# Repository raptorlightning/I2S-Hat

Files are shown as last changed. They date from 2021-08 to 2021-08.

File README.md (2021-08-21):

# I<sup>2</sup>SHat
An SPDIF RX and TX I<sup>2</sup>S Hat for the Raspberry Pi 2, 3, 4, etc. -- all versions that uses the same GPIO pinout for I<sup>2</sup>S.

## Overview
This project was developed as a replacement or substitute for the various DSP MCU-based processors available on the market. The goals of the project were:
* Leverage the ever-increasing processing power of the Raspberry Pi platform through CamillaDSP https://github.com/HEnquist/camilladsp for DSP, decoupling the number of filters and processing capability from the available MCU-based solutions.
* Allow digital input and output without resampling or other pre/post-processing.
* Utilize SPDIF from 44.1kHz-192kHz Stereo coaxial and/or optical.
* Automatic detection of the input sample rate and reconfiguration of the digital filters based on the sample rate found.

To make this possible, a combination of software and hardware is required. The schematics and PCB to create the SPDIF hat are provided in KiCAD format in the "I2SHat" folder. Please modify the schematic and PCB as required for component availibility.

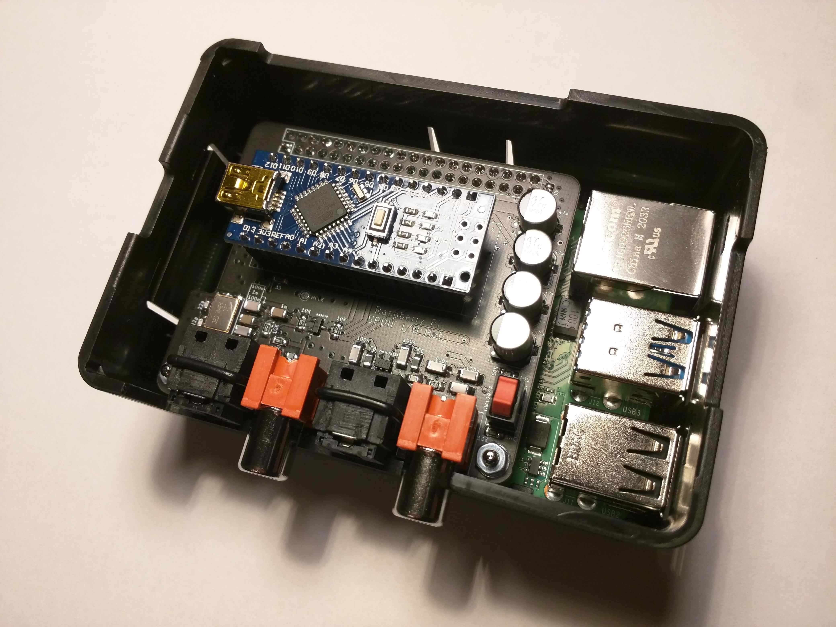
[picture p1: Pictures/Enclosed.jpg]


## Hardware Information
For the PCB, general board rules for sensitive traces should be adhered to as seen in the original design. Extra grounding pads are provided around the SPDIF receiver (WM8804) if physical shielding is needed for nearby EMI components. This has not been a problem with my own testing on a Raspberry Pi 4 Model B above the input buck converter. 
Some BOM cost reductions are as follows:
* Use cheaper 0805 0.1uF X7R decoupling capacitors (>10V), they will work fine with the footprints in the Gerber.
* Don't buffer the inputs before the multiplexer, or use a combined buffer IC. Know the output of your TOSLINK Receiver before you do this.
* Use less expensive decoupling on the output of the 3.3V regulators (see datasheet).

The other aspects of the circuit have been tested and proven. Resistor tolerances are of no concern, neither are capacitor tolerances. Regardless, don't use a 10uF Y5U 5V rated MLCC capacitor for the regulator outputs. That will violate the datasheet.

The SPDIF input and output are tested as shown to work up to 192kHz. Substituting parts (especially the IC types) is discouraged. However, substituing brands or footprints is okay. For example, on the board there is an NXP part in a very small package that is simply a 2:1 LVCMOS mux - NC7SZ157P6X, same as a 74LVC1G157. If you can find a similar part available in a bigger footprint, please edit the board and substitute. The part package size was due to current availability. Only subsitute the unbuffered and buffered inverters on the SPDIF Coaxial input for appropriate unbuffered and buffered parts from other suppliers. Please maintain phase of inputs and outputs if you substitute multi-gate chips and redesign the board.

The footprints provided for TOSLINK are for the TORX142L and TOTX142L, available currently as the Ali-sourced DLR2180 and DLT2180. Unfortunately the market for US/EU TOSLINK receivers at 25mbps bandwidth is largely dead, and the only source is Aixin. Everlight and Toshiba both no longer produce these modules. If you are sourcing from Aixin, ensure that you order a 25mbps module (DLx2xxx) to guarantee 192kHz operation (192*32(Bits/channel)*2(Channels)*2(BMC)=24.576MHz). Modify the footprints as necessary for the TOSLINK module you purchase.

There is a switch on the PCB for the receiver side to choose SPDIF coaxial or TOSLINK input. This is required but can be wired as desired, autodetection is possible, with great modification in hardware or software, but not advised. Generally, one would set up a system with this DSP in a path of specific choosing. The footprint is provided for a GW12RCP equivalent 0.1" microswitch; however, this could be wired to a front panel switch or the Nano itself with further programming and external control. Note that the silkscreen is correct for the switch, but opposite of the connected pads due to the switch mechanics.

If the HifiBerry case (https://www.hifiberry.com/shop/cases/hifiberry-universal-case-black-pi4/) is used, you will need to trim the TOSLINK devices specified. There are 192kHz (25Mbps) TOSLINK transmitters and receivers available from overseas sources in quantity without the screw mounting terminal, but the DLR2180 and DLT2180 TOXX142L equivalents generally have good availability. If you use these substitutes, trim off the screw terminal and add mechanical strength with solid-core wire through the provided holes on the board as shown. If the HifiBerry case is used, pressing down on the top of the case resets the Nano and the WM8804, which might be useful if your Pi takes longer than 45 seconds to start and you don't modify the code (see the INO). There is diode protection for the 5V supply, so you should be able to program the Nano in-circuit (no warranty...) The Pi+Hat+Nano stack is designed to fit in the HifiBerry case with a little extra filing for the TOSLINK connectors on the bottom of the cutout. Height is tight, but it does fit using the standard height board headers specified.

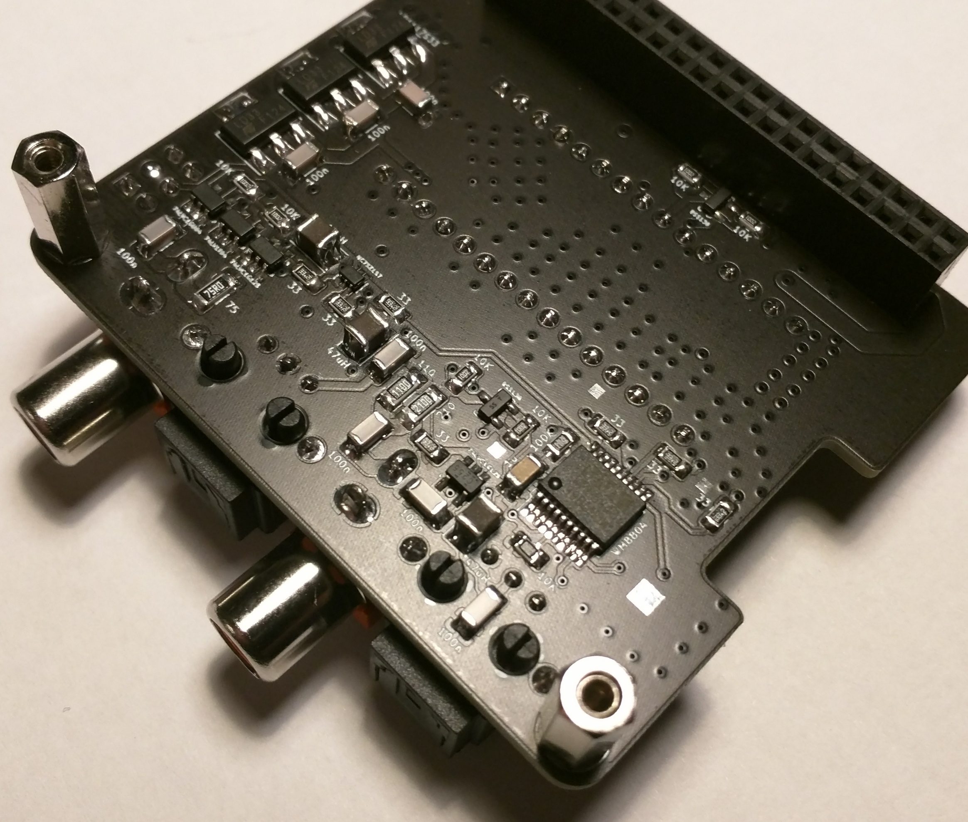
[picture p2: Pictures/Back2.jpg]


## Software Information

You will need to flash the project INO file to an Arduino Nano for control of the WM8804 and sample rate detection. The code and functionality could likely be accomplished with an ATTINY, but for the price and seeing as the footprint fits, a Nano is adequate. See the Arduino documentation for proper flashing of the INO file. Modify as you need for your purposes. 

On the software side of things, the Raspberry Pi must be responsible for receiving I<sup>2</sup>S data, transmitting I<sup>2</sup>S data, and processing it in the middle. Using Ubuntu Server, with a DTS overlay for slave I<sup>2</sup>S operation:

The tested system consists of Ubuntu Server 20.04.2 LTS running on a Raspberry Pi Model 4B. Modifications are posted below:
* Install the required I<sup>2</sup>S Slave DTOverlay at https://github.com/AkiyukiOkayasu/RaspberryPi_I2S_Slave
* Set up CamillaDSP to run as a service on boot through the Python script in the repostiory. There are many different ways to accomplish this, but how it has been tested is through the following (sudo assumed):
  1. Setup WiFi and SSH. I won't illustrate that here as there are many guides available online for it.
  2. Copy the CamillaDSP executable (appropriate to your arch (for RPi4B and Ubuntu Server, it should be aarch64)), startdsp.py, and all of your frequency-specific YML files to a created /etc/camilladsp/ directory.
  3. Create a file in the /etc/systemd/system directory called camilladsp.service that contains the following code:
    * ```
      [Unit]
      Description=CamillaDSP Script Booter
      After=multi-user.target

      [Service]
      ExecStart=/usr/bin/python3 /etc/camilladsp/startdsp.py
      #ExecStart=cat
      StandardOutput=kmsg
      StandardError=kmsg
      Restart=always
      CPUSchedulingPolicy=rr
      CPUSchedulingPriority=99
      IOSchedulingClass=realtime
      IOSchedulingPriority=0

      [Install]
      WantedBy=multi-user.target
    * This ensures that the process (and hopefully subprocess of CamillaDSP) runs without any interruption due to other system services. The point of installing Ubuuntu server is that you will have very few, if any, processes running in the background. All CPU should be dedicated to the DSP.
  4. In the /etc/systemd/system/multi-user.target.wants directory create a symlink using "ln" camilladsp.service to /etc/systemd/system/camilladsp.service to create a link for the target.
* Modify the following in the /boot/firmware directory to enable I<sup>2</sup>S and disable onboard audio (unless you need it).
    * /boot/firmware/syscfg.txt
      *  ```
          \# This file is intended to be modified by the pibootctl utility. User
          \# configuration changes should be placed in "usercfg.txt". Please refer to the
          \# README file for a description of the various configuration files on the boot
          \# partition.

          \#enable_uart=1
          \#dtparam=audio=on
          \#dtparam=i2c_arm=on
          \#dtparam=spi=on
          dtparam=i2s=on
          cmdline=cmdline.txt
          
* Headers for YML files for CamillaDSP include the following since the required DTOverlay is installed (obviously samplerate is file-dependent):
    * ```---
      #You may need to specify chunksize (1024) and target_level (512). See default files and CamillaDSP documentation.
      
      devices:
        samplerate: 44100
        chunksize: 1024
        target_level: 512
        capture:
          type: Alsa
          channels: 2
          device: "hw:CARD=GenericStereoAu,DEV=1"
          format: S32LE
        playback:
          type: Alsa
          channels: 2
          device: "hw:CARD=GenericStereoAu,DEV=0"
          format: S32LE
    
* Set up a Samba share for the /etc/camilladsp directory if you want to remotely access it for uploading new configurations.

## Notes and Addendum
Please play around with the files and let me know if you have any better ideas! At heart, I'm a hardware guy, I make the software to work for what I need but don't go beyond. If you have a better solution for the software or find any holes in my instructions, please reach out. I would like to make this as straightforward as possible for anyone to use.

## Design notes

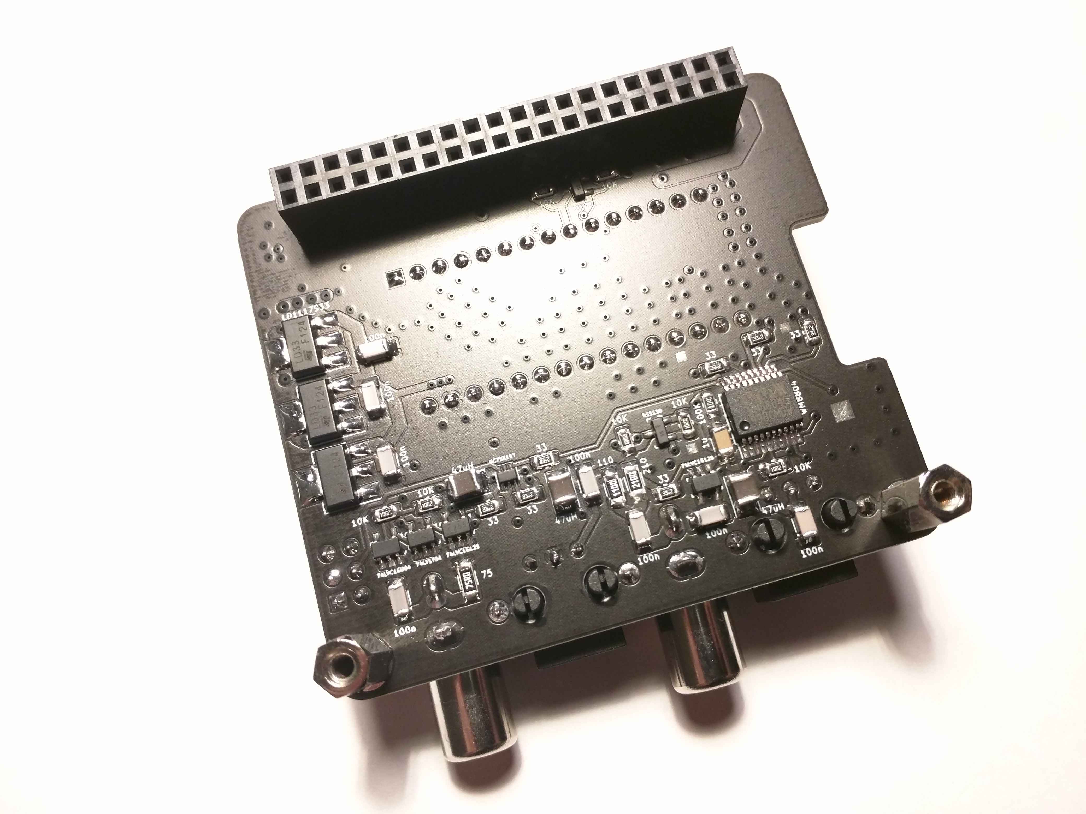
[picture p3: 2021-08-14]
Pictures/Back.jpg

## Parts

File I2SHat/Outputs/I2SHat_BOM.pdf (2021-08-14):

I2SHat

X1 | X2 | Item | Qty | Reference(s) | Value | Footprint
| | 1 | 1 | A1 | Arduino_Nano_v3.x | Module:Arduino_Nano
| | 2 | 16 | C1, C2, C3, C4, C5, C6, C7, C8, C9, C10, C11, C14, C18, C20, C22, C24 | 100n | Capacitor_SMD:C_1206_3216Metric_Pad1.33x1.80mm_HandSolder
| | 3 | 3 | C12, C13, C17 | 1u | Capacitor_SMD:C_1206_3216Metric_Pad1.33x1.80mm_HandSolder
| | 4 | 2 | C15, C16 | 22p | Capacitor_SMD:C_0603_1608Metric_Pad1.08x0.95mm_HandSolder
| | 5 | 4 | C19, C21, C23, C25 | 47u | Capacitor_SMD:C_Elec_6.3x5.8
| | 6 | 1 | D1 | SS1P3L-M3/84A | SS1P3L:SS1P3L-M3&slash_84A
| | 7 | 4 | FB1, FB2, FB3, FB4 | Ferrite_Bead_Small | Resistor_SMD:R_0805_2012Metric_Pad1.20x1.40mm_HandSolder
| | 8 | 2 | H1, H2 | MountingHole | MountingHole:MountingHole_2.7mm_M2.5_Pad
| | 9 | 1 | J1 | TORX142L | Mouser:PLR135T9
| | 10 | 1 | J2 | TOTX142L | Mouser:PLR135T9
| | 11 | 1 | J3 | TX_RCA | Mouser:CUI_RCJ-04X
| | 12 | 1 | J4 | Raspberry_Pi_2_3 | Connector_PinHeader_2.54mm:PinHeader_2x20_P2.54mm_Vertical
| | 13 | 1 | J5 | RX_RCA | Mouser:CUI_RCJ-04X
| | 14 | 3 | L1, L2, L3 | 47uH | Inductor_SMD:L_Taiyo-Yuden_NR-24xx_HandSoldering
| | 15 | 5 | Q1, Q2, Q3, Q4, Q5 | BSS138 | digikey-footprints:SOT-23-3
| | 16 | 10 | R1, R2, R3, R5, R10, R21, R22, R23, R26, R27 | 33 | Resistor_SMD:R_0805_2012Metric_Pad1.20x1.40mm_HandSolder
| | 17 | 17 | R4, R6, R9, R11, R13, R14, R15, R16, R17, R18, R19, R20, R24, R25, R28, R29, R31 | 10K | Resistor_SMD:R_0805_2012Metric_Pad1.20x1.40mm_HandSolder
| | 18 | 1 | R7 | 210 | Resistor_SMD:R_1206_3216Metric_Pad1.30x1.75mm_HandSolder
| | 19 | 1 | R8 | 110 | Resistor_SMD:R_1206_3216Metric_Pad1.30x1.75mm_HandSolder
| | 20 | 1 | R12 | 75 | Resistor_SMD:R_1206_3216Metric_Pad1.30x1.75mm_HandSolder
| | 21 | 1 | R30 | 100K | Resistor_SMD:R_0805_2012Metric_Pad1.20x1.40mm_HandSolder
| | 22 | 2 | R32, R33 | 110 | Resistor_SMD:R_0805_2012Metric_Pad1.20x1.40mm_HandSolder
| | 23 | 1 | SW1 | GW12RCP | Button_Switch_THT:SW_NKK_G1xJP
| | 24 | 3 | U1, U3, U4 | 74LVC1G125DBV | digikey-footprints:SOT-753
| | 25 | 1 | U2 | NC7SZ157P6X | Package_TO_SOT_SMD:SOT-363_SC-70-6
| | 26 | 1 | U5 | 74LVC1GU04DBV | digikey-footprints:SOT-753
| | 27 | 1 | U6 | 74LV1T04DBV | digikey-footprints:SOT-753
| | 28 | 1 | U7 | WM8804 | Package_SO:SSOP-20_5.3x7.2mm_P0.65mm
| | 29 | 1 | U8 | SN74LV1T34DBV | digikey-footprints:SOT-753
| | 30 | 3 | U9, U10, U11 | LD1117S33 | Package_TO_SOT_SMD:SOT-223-3_TabPin2
| | 31 | 1 | Y1 | ABMM-12.000MHZ | Crystal:Crystal_SMD_7050-4Pin_7.0x5.0mm

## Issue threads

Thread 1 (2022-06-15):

Symbol library cache file is missing

nikitalita, 2022-06-15:
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

This means there are a lot of missing symbols in the schematic, like so:
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

raptorlightning, 2022-08-28:
Uploaded symbol cache, thanks!

Closed 2022-08-28.

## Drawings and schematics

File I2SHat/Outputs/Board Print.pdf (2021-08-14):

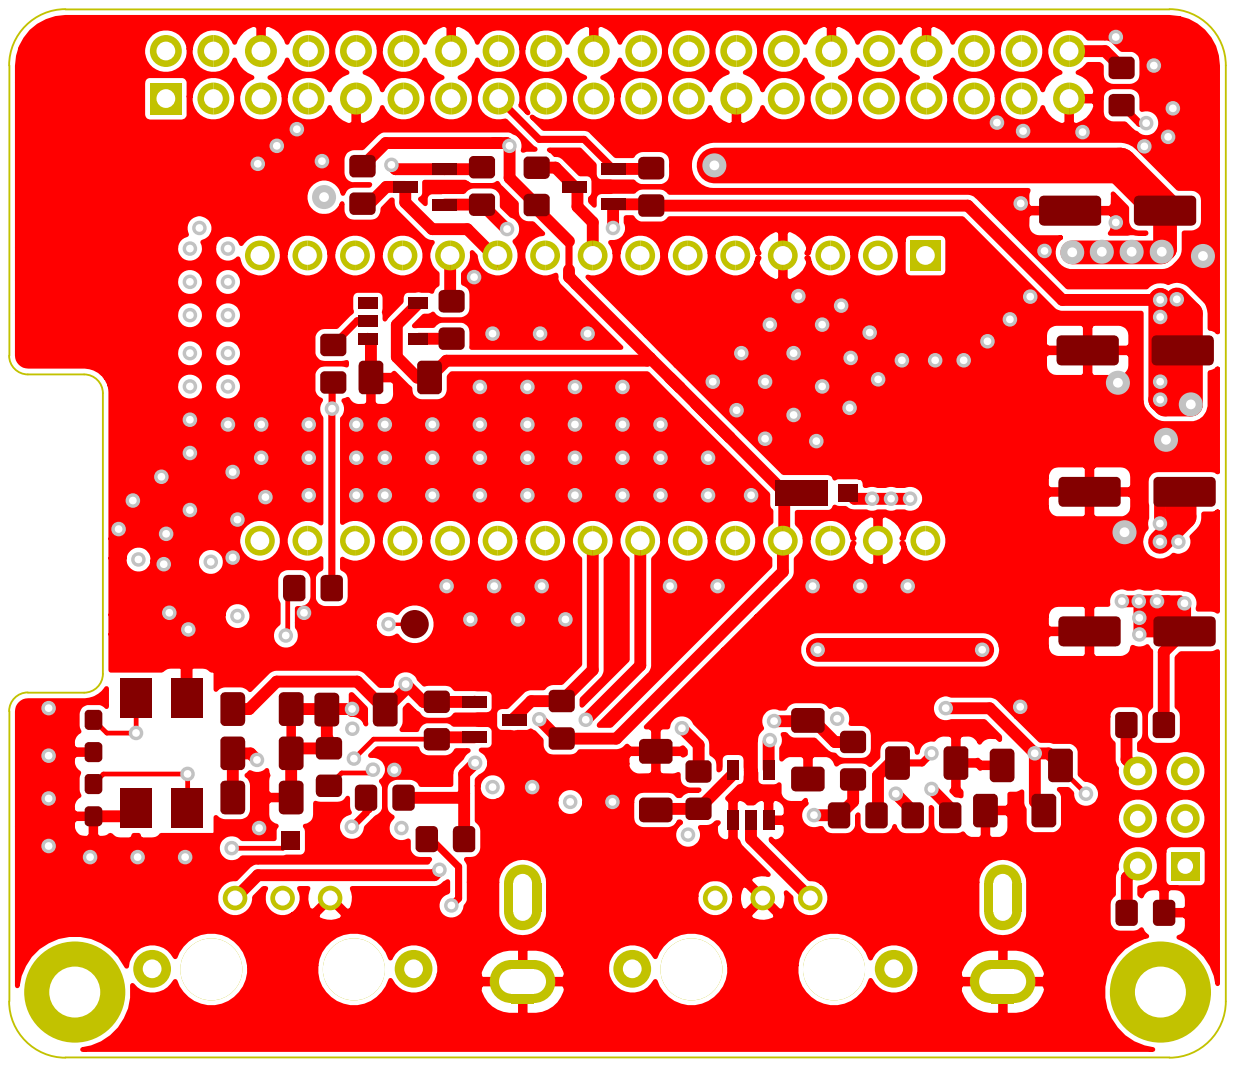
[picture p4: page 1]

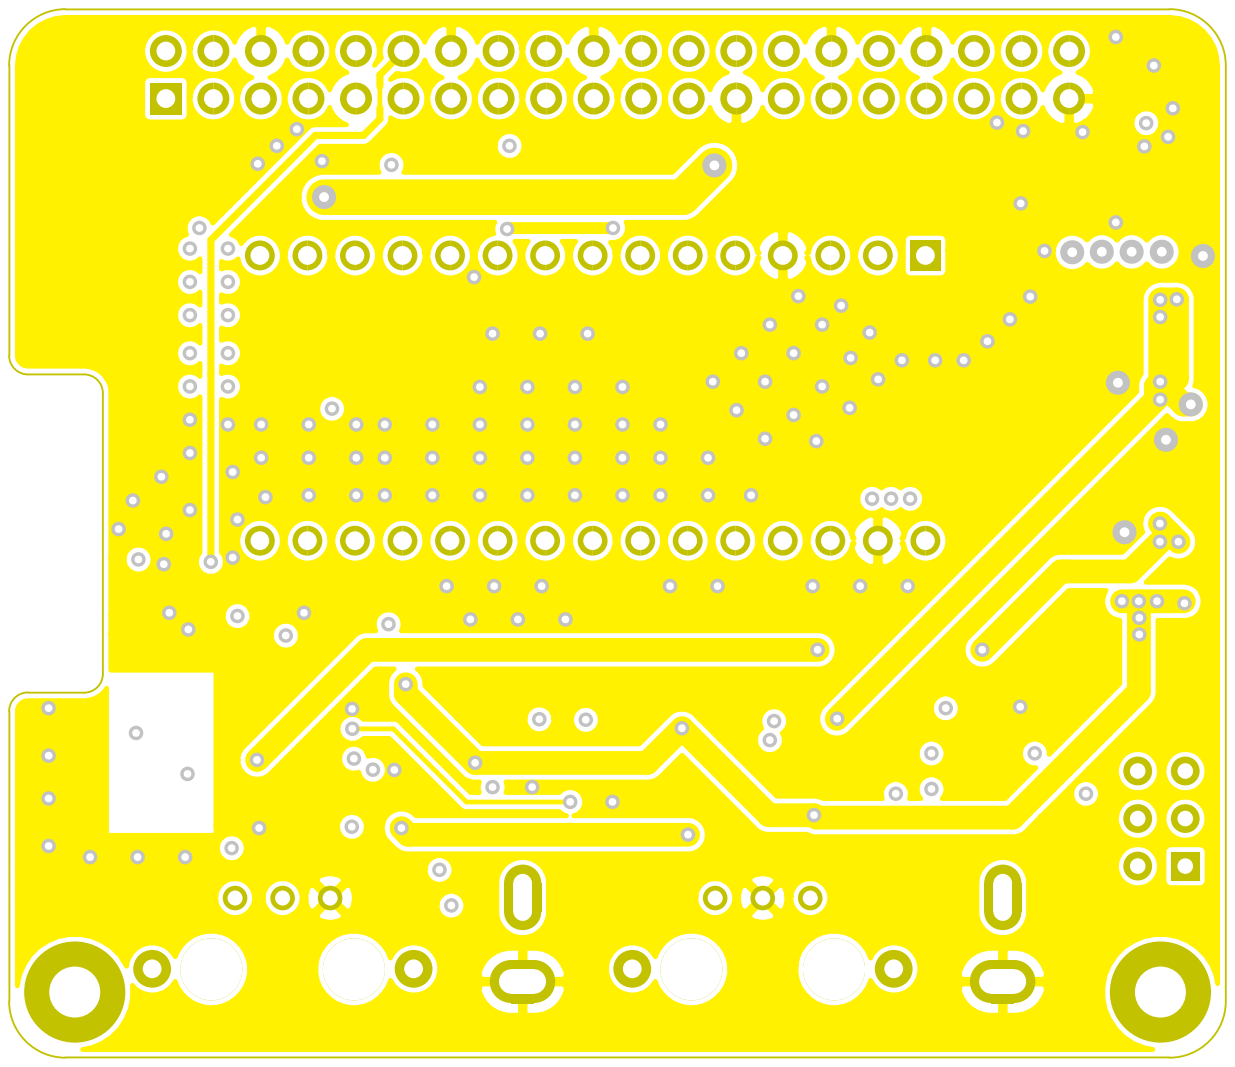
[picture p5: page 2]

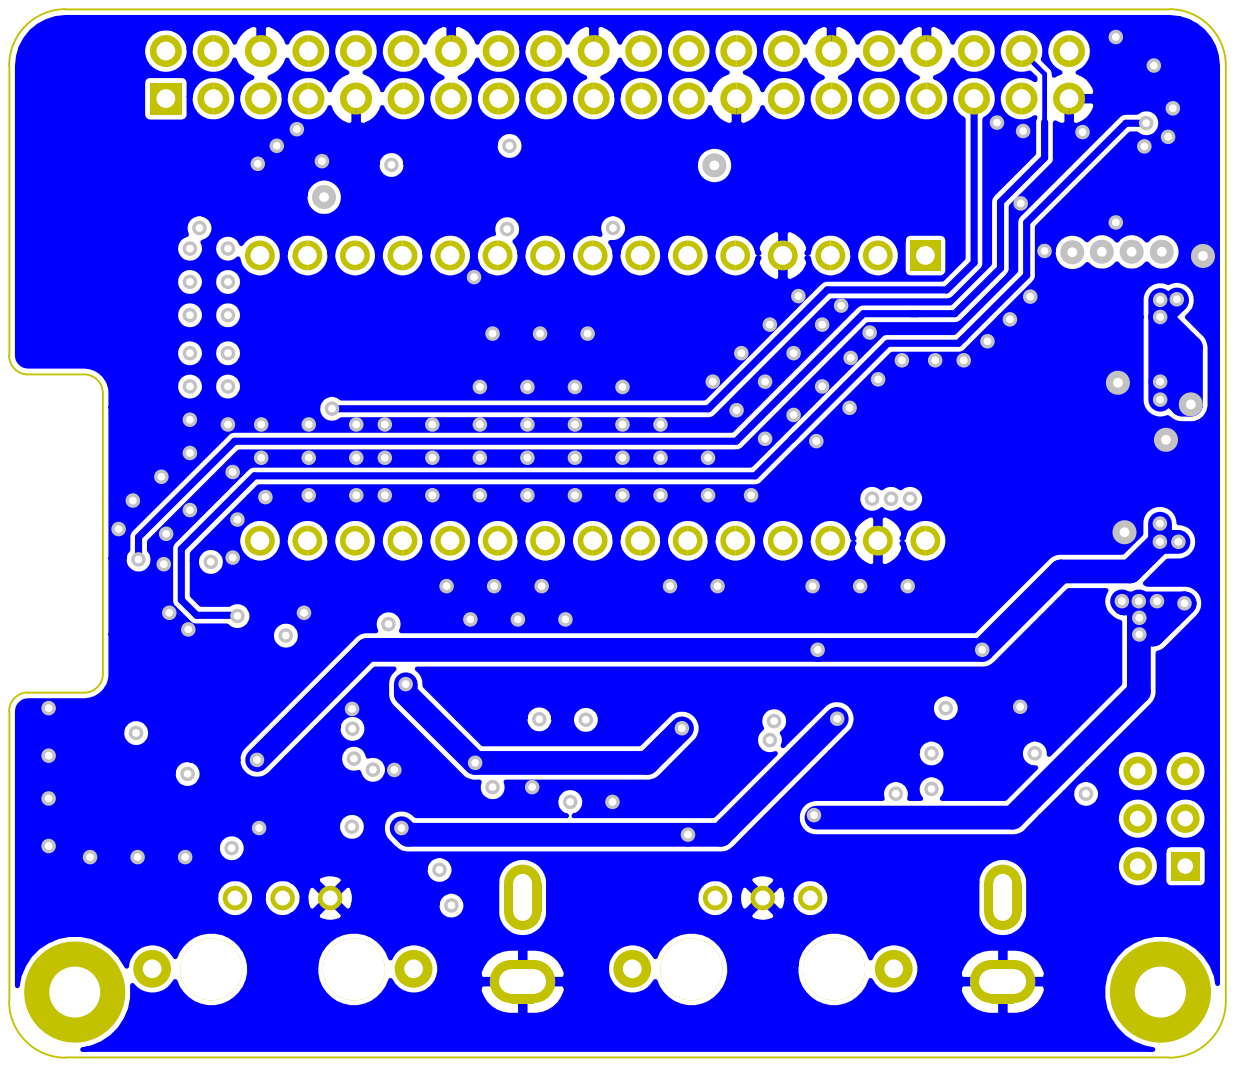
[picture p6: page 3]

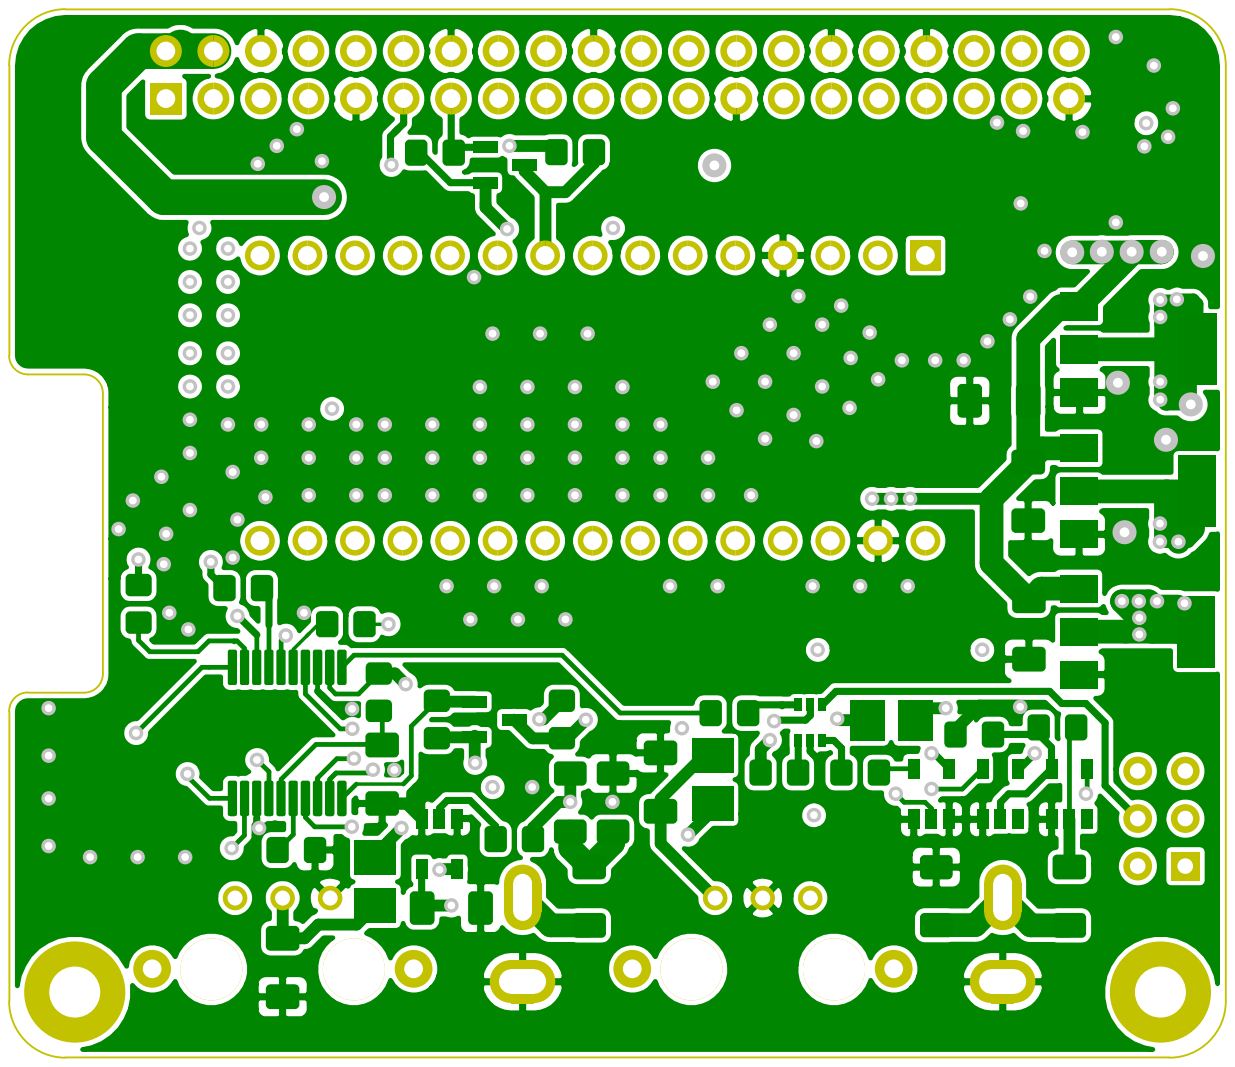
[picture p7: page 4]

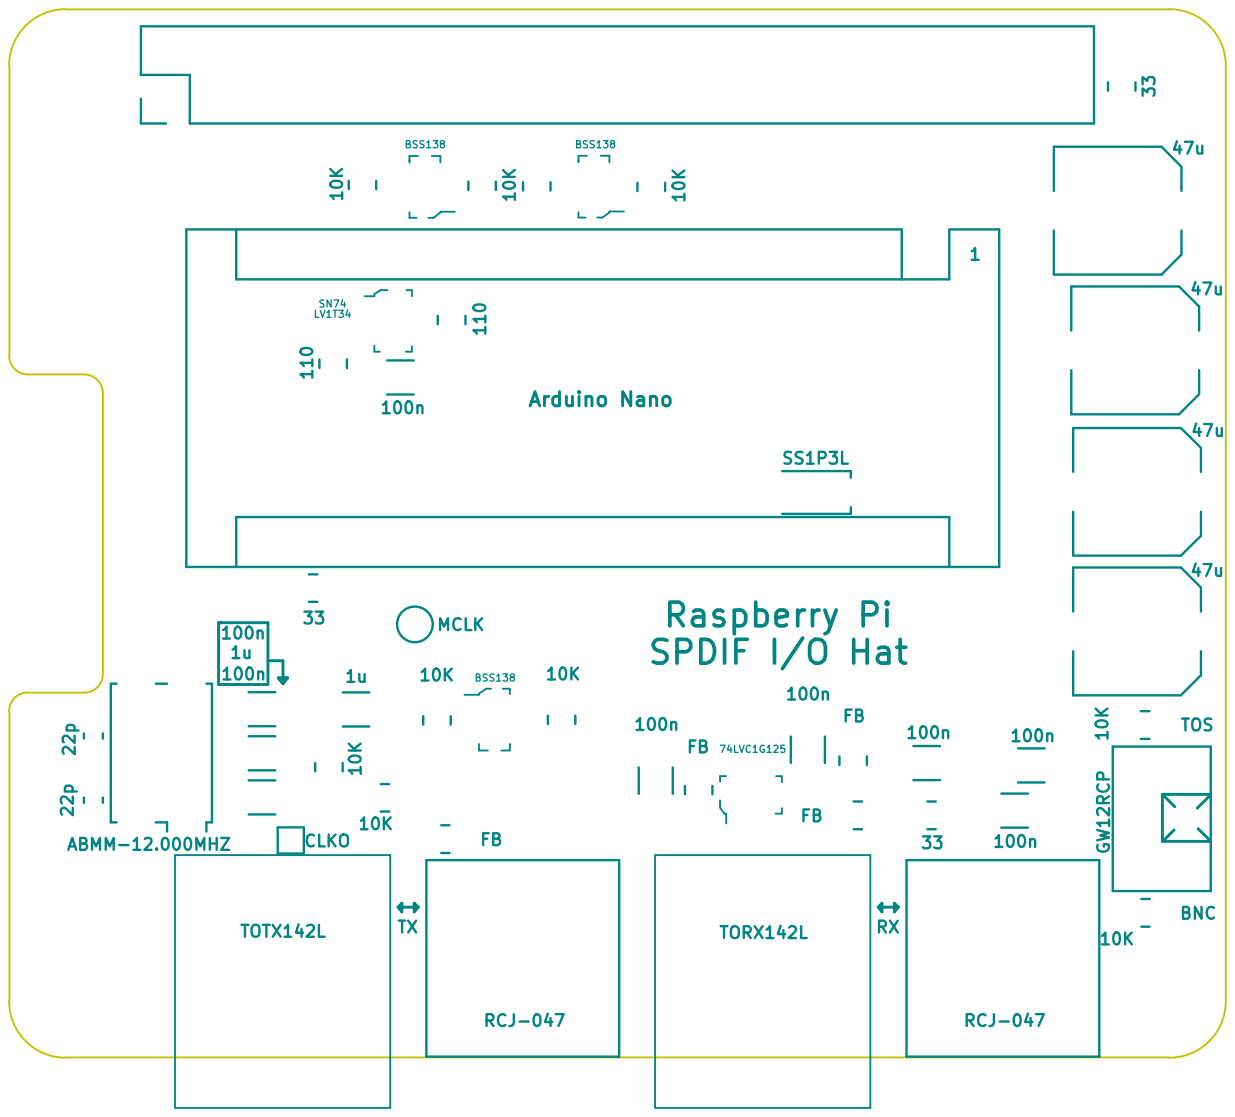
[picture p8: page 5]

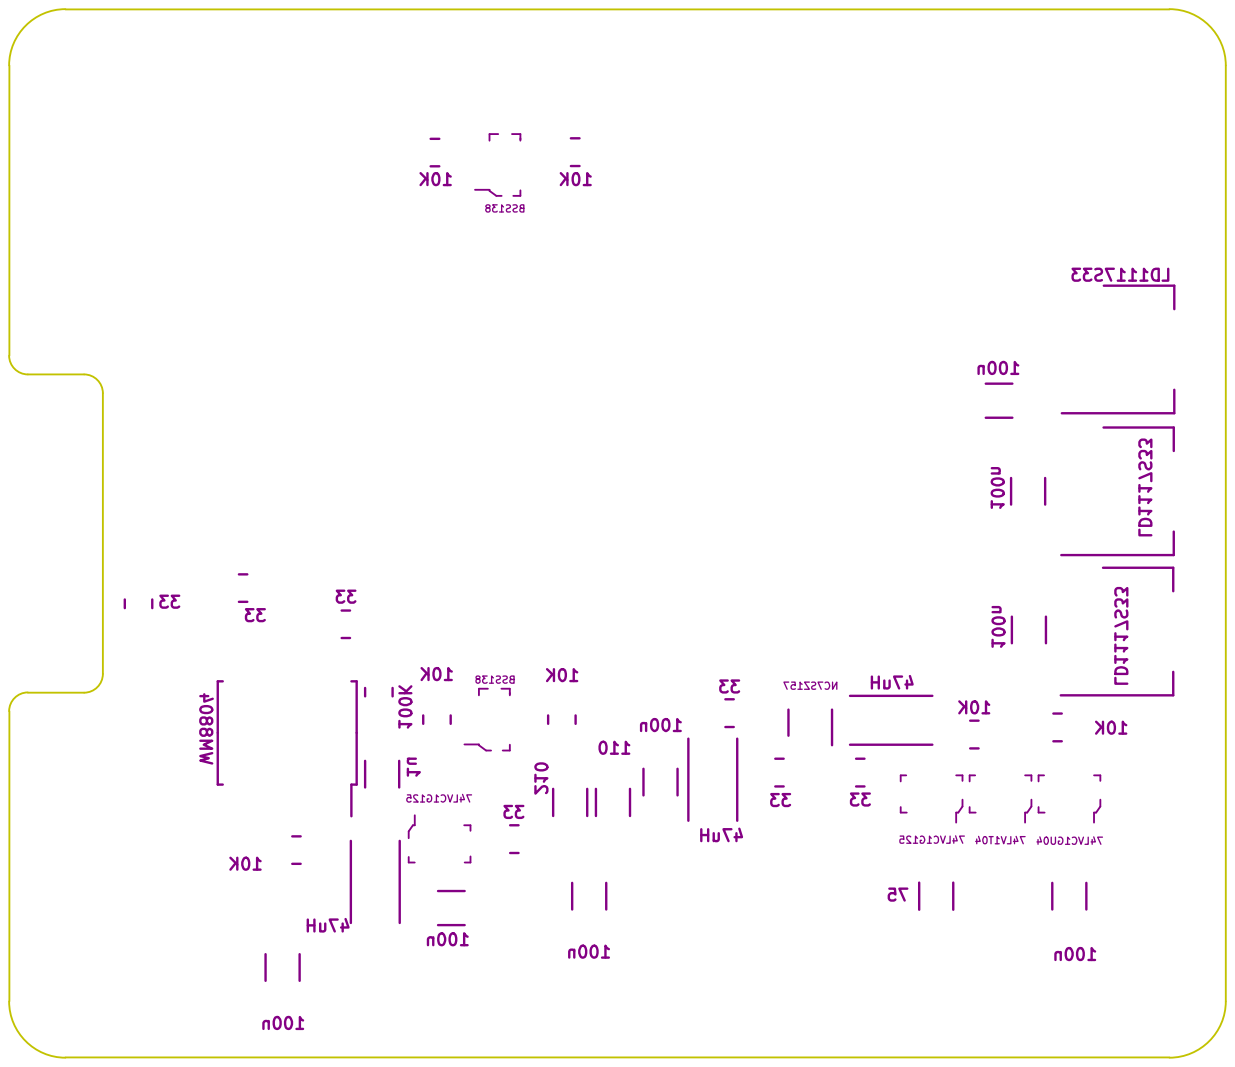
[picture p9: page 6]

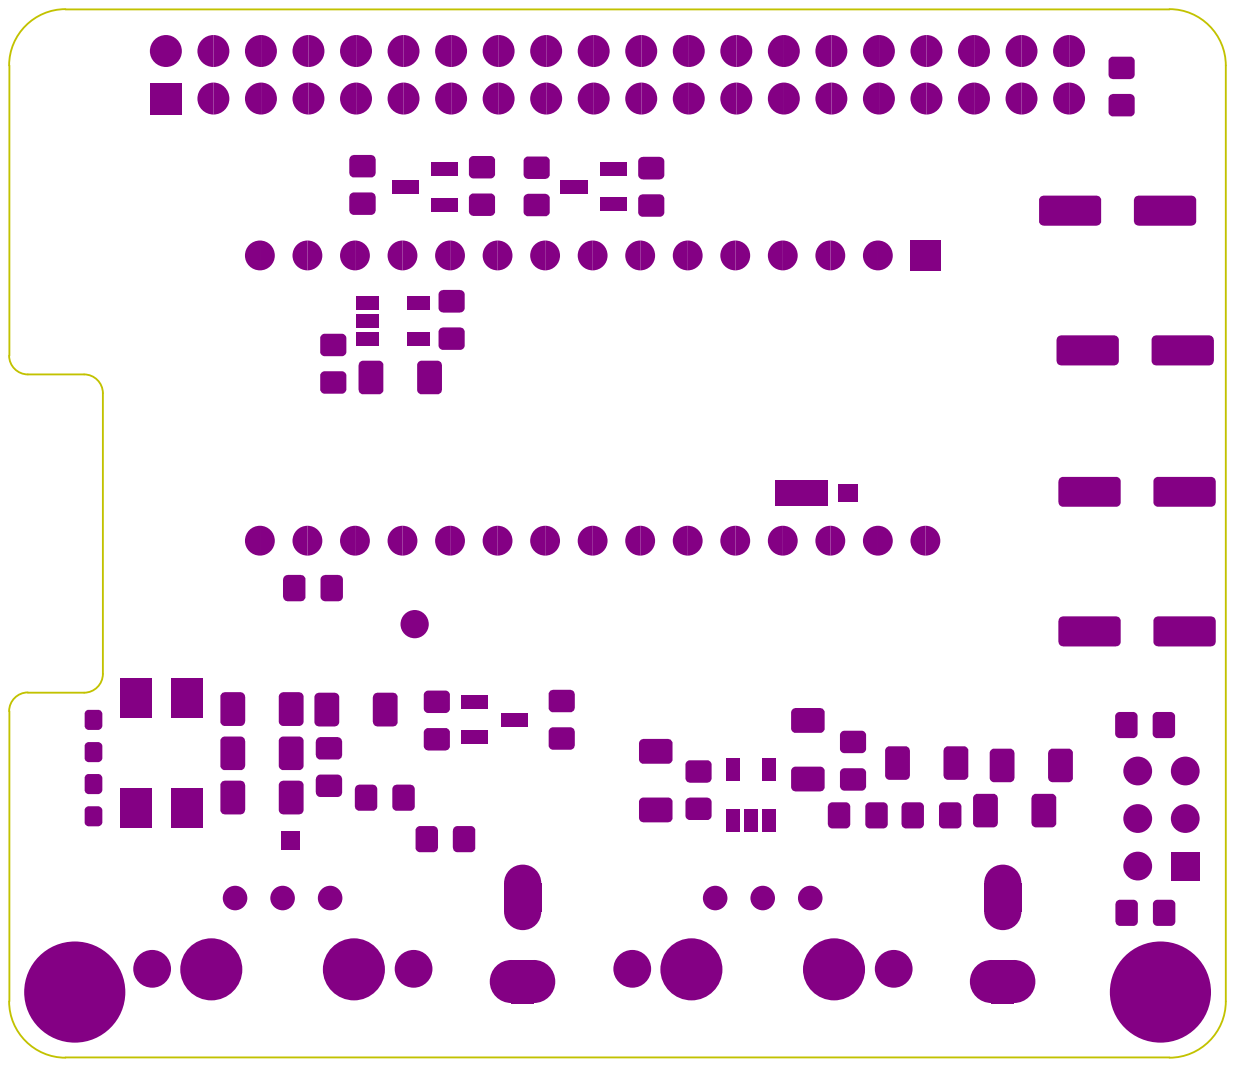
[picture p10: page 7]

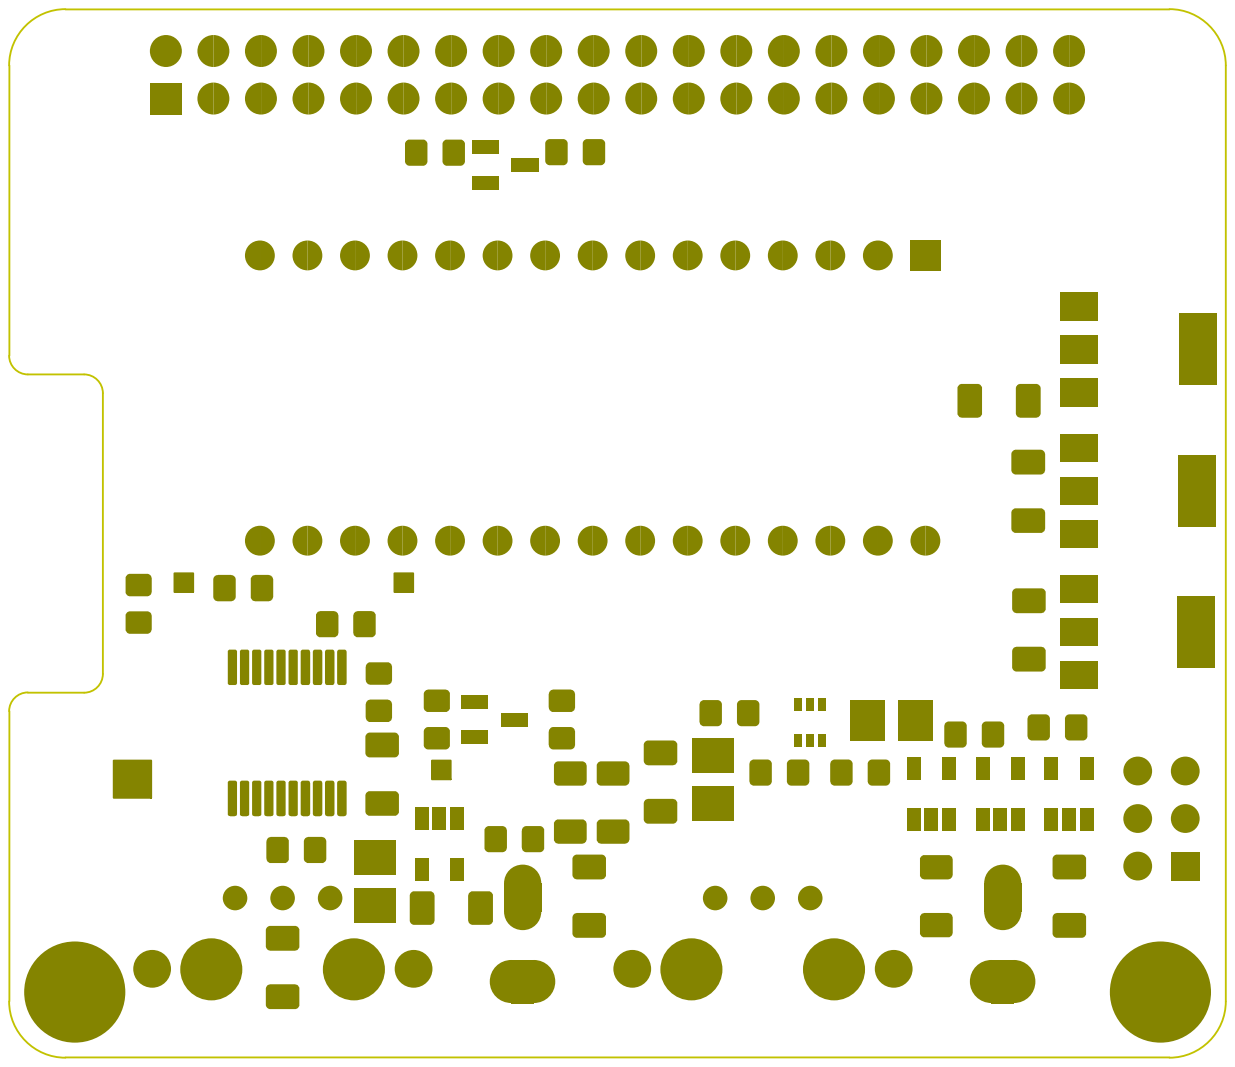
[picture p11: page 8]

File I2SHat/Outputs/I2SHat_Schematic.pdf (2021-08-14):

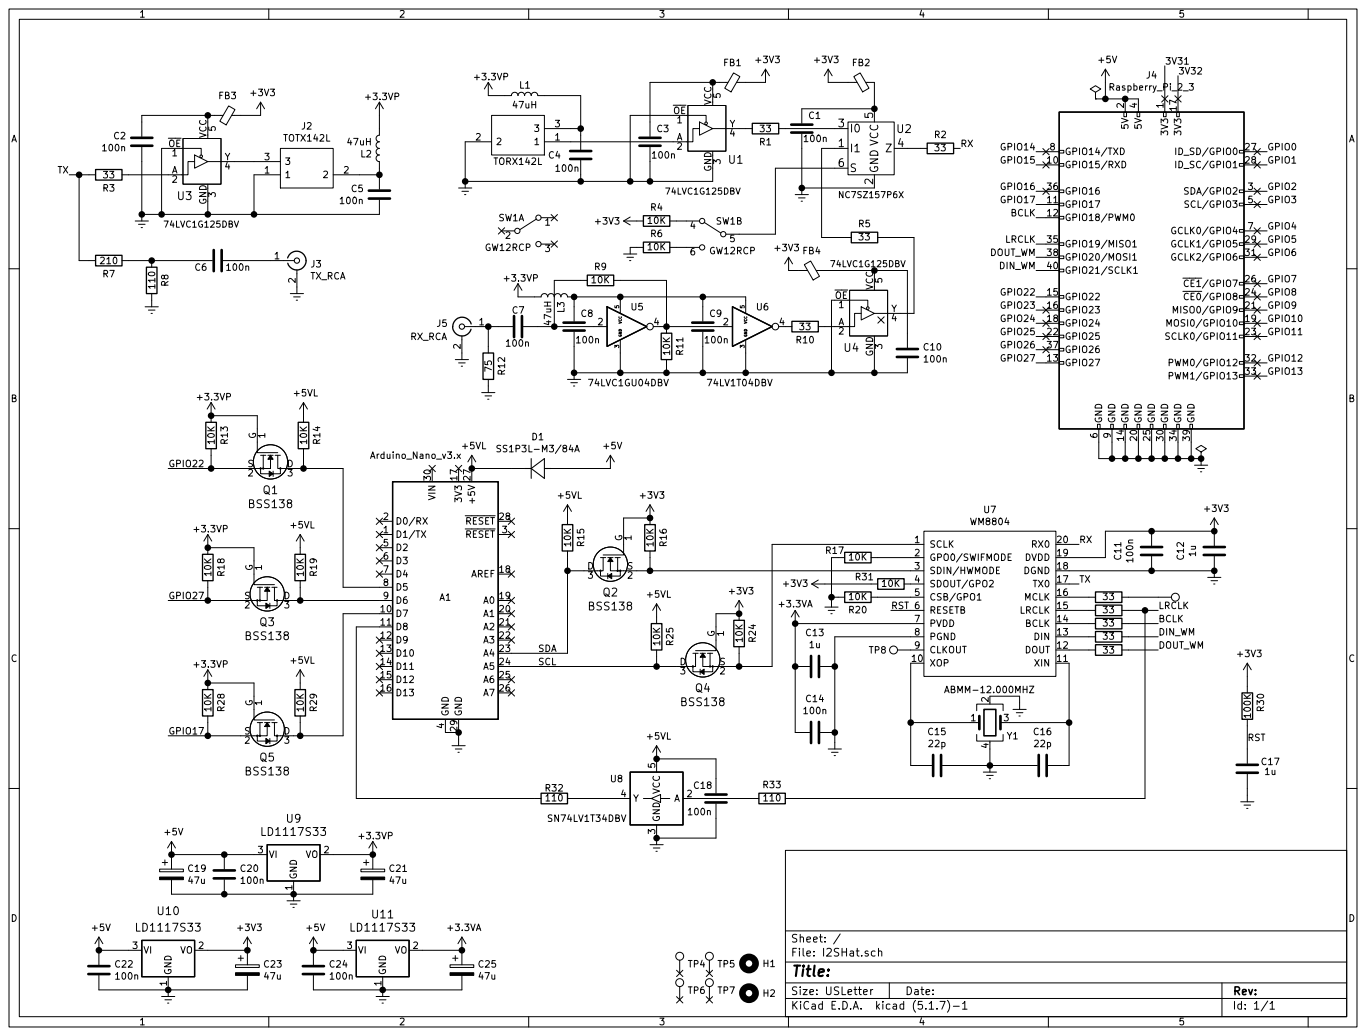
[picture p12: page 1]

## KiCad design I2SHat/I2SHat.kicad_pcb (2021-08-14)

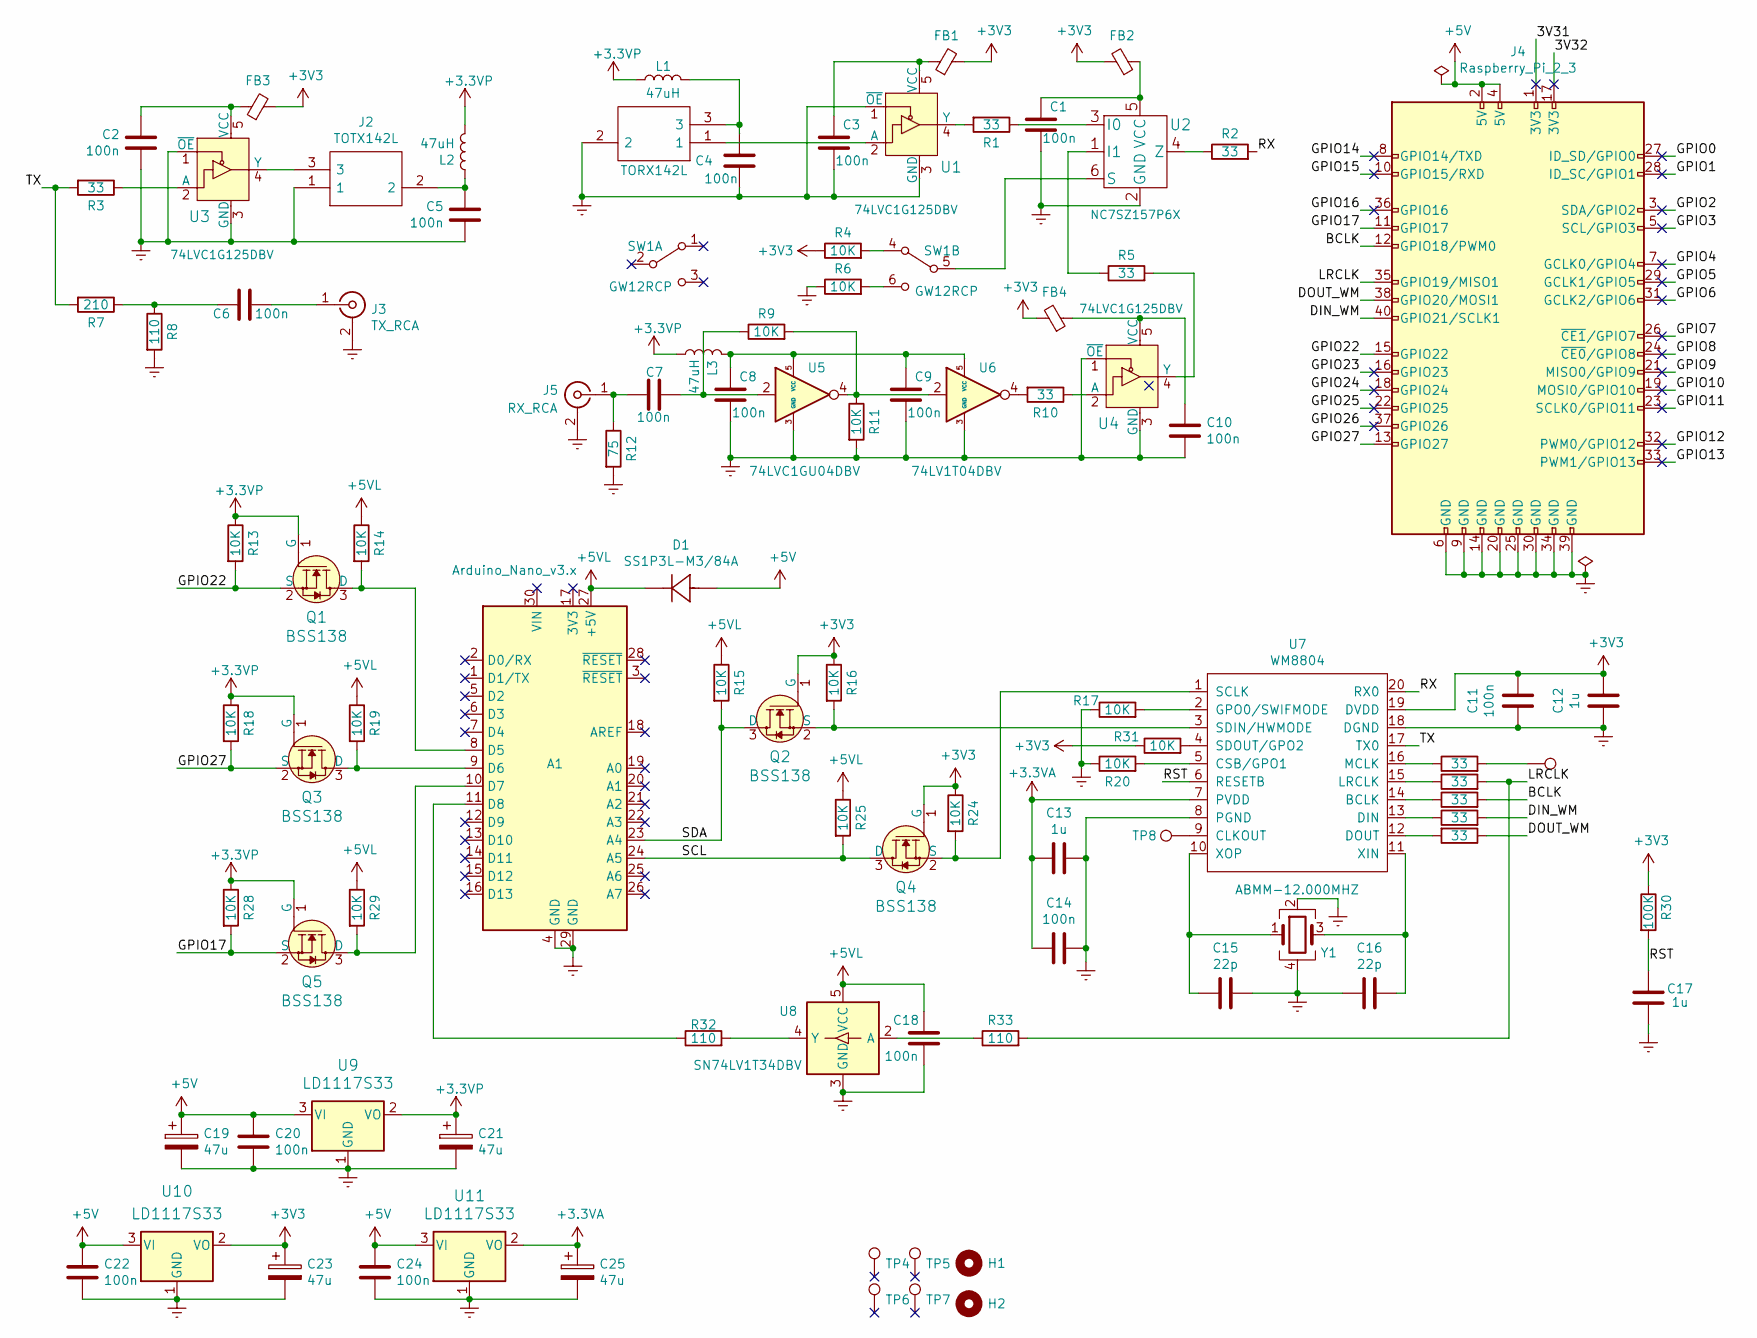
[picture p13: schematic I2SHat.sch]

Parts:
A1: Arduino_Nano_v3.x; Arduino_Nano
C1, C2, C3, C4, C5, C6, C7, C8, C9, C10, C11, C14, C18, C20, C22, C24: 100n; C_1206_3216Metric_Pad1.33x1.80mm_HandSolder
C12, C13, C17: 1u; C_1206_3216Metric_Pad1.33x1.80mm_HandSolder
C15, C16: 22p; C_0603_1608Metric_Pad1.08x0.95mm_HandSolder
C19, C21, C23, C25: 47u; C_Elec_6.3x5.8; Mouser Part Number 667-EEH-ZA1E470P
D1: SS1P3L-M3/84A; SS1P3L-M3&slash_84A
FB1, FB2, FB3, FB4: Ferrite_Bead_Small; R_0805_2012Metric_Pad1.20x1.40mm_HandSolder
H1, H2: MountingHole; MountingHole_2.7mm_M2.5_Pad
J1: TORX142L; PLR135T9; Mouser Part Number 638-PLR135T9
J2: TOTX142L; PLR135T9; Mouser Part Number 638-PLR135T9
J3: TX_RCA; CUI_RCJ-04X
J4: Raspberry_Pi_2_3; PinHeader_2x20_P2.54mm_Vertical
J5: RX_RCA; CUI_RCJ-04X
L1, L2, L3: 47uH; L_Taiyo-Yuden_NR-24xx_HandSoldering; Mouser Part Number 963-CB2518T470K
Q1, Q2, Q3, Q4, Q5: BSS138; SOT-23-3; MPN BSS138-7-F; Digi-Key_PN BSS138-FDICT-ND
R1, R2, R3, R5, R10, R21, R22, R23, R26, R27: 33; R_0805_2012Metric_Pad1.20x1.40mm_HandSolder
R4, R6, R9, R11, R13, R14, R15, R16, R17, R18, R19, R20, R24, R25, R28, R29, R31: 10K; R_0805_2012Metric_Pad1.20x1.40mm_HandSolder
R7: 210; R_1206_3216Metric_Pad1.30x1.75mm_HandSolder
R8: 110; R_1206_3216Metric_Pad1.30x1.75mm_HandSolder
R12: 75; R_1206_3216Metric_Pad1.30x1.75mm_HandSolder
R30: 100K; R_0805_2012Metric_Pad1.20x1.40mm_HandSolder
R32, R33: 110; R_0805_2012Metric_Pad1.20x1.40mm_HandSolder
SW1: GW12RCP; SW_NKK_G1xJP
TP2: TestPoint; TestPoint_Pad_D1.5mm
TP4, TP5, TP6, TP7: TestPoint; TestPoint_NoSilk_D2.50mm_Drill1.0mm
TP8: TestPoint; TestPoint_Pad_1.0x1.0mm
U1, U3, U4: 74LVC1G125DBV; SOT-753; MPN NC7SZ125M5X; Digi-Key_PN NC7SZ125M5XCT-ND
U2: NC7SZ157P6X; SOT-363_SC-70-6
U5: 74LVC1GU04DBV; SOT-753
U6: 74LV1T04DBV; SOT-753
U7: WM8804; SSOP-20_5.3x7.2mm_P0.65mm
U8: SN74LV1T34DBV; SOT-753
U9, U10, U11: LD1117S33; SOT-223-3_TabPin2; MPN LD1117S33CTR; Digi-Key_PN 497-1241-1-ND
Y1: ABMM-12.000MHZ; Crystal_SMD_7050-4Pin_7.0x5.0mm

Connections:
+3.3VA: C13.1, C14.1, C25.1, U7.7 (PVDD), U11.2 (VO)
+3.3VP: C21.1, L1.1, L2.2, L3.1, Q1.1 (G), Q3.1 (G), Q5.1 (G), R13.1, R18.1, R28.1, U9.2 (VO)
+3V3: C11.2, C12.2, C23.1, FB1.2, FB2.2, FB3.2, FB4.2, Q2.1 (G), Q4.1 (G), R4.1, R16.1, R24.1, R30.1, R31.1, U7.19 (DVDD), U10.2 (VO)
+5V: C19.1, C20.1, C22.1, C24.1, D1.2, J4.2 (5V), J4.4 (5V), U9.3 (VI), U10.3 (VI), U11.3 (VI)
+5VL: A1.27 (+5V), C18.1, D1.1, R14.1, R15.1, R19.1, R25.1, R29.1, U8.5 (VCC)
/3V31: J4.1 (3V3)
/3V32: J4.17 (3V3)
/BCLK: J4.12 (GPIO18/PWM0), R23.2
/DIN_WM: J4.40 (GPIO21/SCLK1), R26.2
/DOUT_WM: J4.38 (GPIO20/MOSI1), R27.1
/GPIO0: J4.27 (ID_SD/GPIO0)
/GPIO1: J4.28 (ID_SC/GPIO1)
/GPIO2: J4.3 (SDA/GPIO2)
/GPIO3: J4.5 (SCL/GPIO3)
/GPIO4: J4.7 (GCLK0/GPIO4)
/GPIO5: J4.29 (GCLK1/GPIO5)
/GPIO6: J4.31 (GCLK2/GPIO6)
/GPIO7: J4.26 (~CE1~/GPIO7)
/GPIO8: J4.24 (~CE0~/GPIO8)
/GPIO9: J4.21 (MISO0/GPIO9)
/GPIO10: J4.19 (MOSI0/GPIO10)
/GPIO11: J4.23 (SCLK0/GPIO11)
/GPIO12: J4.32 (PWM0/GPIO12)
/GPIO13: J4.33 (PWM1/GPIO13)
/GPIO14: J4.8 (GPIO14/TXD)
/GPIO15: J4.10 (GPIO15/RXD)
/GPIO16: J4.36 (GPIO16)
/GPIO17: J4.11 (GPIO17), Q5.2 (S), R28.2
/GPIO22: J4.15 (GPIO22), Q1.2 (S), R13.2
/GPIO23: J4.16 (GPIO23)
/GPIO24: J4.18 (GPIO24)
/GPIO25: J4.22 (GPIO25)
/GPIO26: J4.37 (GPIO26)
/GPIO27: J4.13 (GPIO27), Q3.2 (S), R18.2
/LRCLK: J4.35 (GPIO19/MISO1), R22.2, R33.2
/RST: C17.2, R30.2, U7.6 (RESETB)
/RX: R2.2, U7.20 (RX0)
/SCL: A1.24 (A5), Q4.3 (D), R25.2
/SDA: A1.23 (A4), Q2.3 (D), R15.2
/TX: R3.2, R7.2, U7.17 (TX0)
GNDREF: A1.4 (GND), A1.29 (GND), C1.2, C2.2, C3.2, C4.2, C5.2, C8.2, C9.2, C10.2, C11.1, C12.1, C13.2, C14.2, C15.2, C16.1, C17.1, C18.2, C19.2, C20.2, C21.2, C22.2, C23.2, C24.2, C25.2, J1.2, J2.1, J3.2 (Ext), J4.6 (GND), J4.9 (GND), J4.14 (GND), J4.20 (GND), J4.25 (GND), J4.30 (GND), J4.34 (GND), J4.39 (GND), J5.2 (Ext), R6.1, R8.2, R11.2, R12.2, R17.1, R20.1, U1.1 (~OE), U1.3 (GND), U2.2 (GND), U3.1 (~OE), U3.3 (GND), U4.1 (~OE), U4.3 (GND), U5.3 (GND), U6.3 (GND), U7.8 (PGND), U7.18 (DGND), U8.3 (GND), U9.1 (GND), U10.1 (GND), U11.1 (GND), Y1.2, Y1.4
unnamed: A1.8 (D5), Q1.3 (D), R14.2
unnamed: A1.9 (D6), Q3.3 (D), R19.2
unnamed: A1.10 (D7), Q5.3 (D), R29.2
unnamed: A1.11 (D8), R32.1
unnamed: C1.1, FB2.1, U2.5 (VCC)
unnamed: C2.1, FB3.1, U3.5 (VCC)
unnamed: C3.1, FB1.1, U1.5 (VCC)
unnamed: C4.1, J1.3, L1.2
unnamed: C5.1, J2.2, L2.1
unnamed: C6.1, R7.1, R8.1
unnamed: C6.2, J3.1 (In)
unnamed: C7.1, R9.1, U5.2
unnamed: C7.2, J5.1 (In), R12.1
unnamed: C8.1, C9.1, L3.2, U5.5 (VCC), U6.5 (VCC)
unnamed: C10.1, FB4.1, U4.5 (VCC)
unnamed: C15.1, U7.10 (XOP), Y1.1
unnamed: C16.2, U7.11 (XIN), Y1.3
unnamed: J1.1, U1.2 (A)
unnamed: J2.3, U3.4 (Y)
unnamed: Q2.2 (S), R16.2, U7.3 (SDIN/HWMODE)
unnamed: Q4.2 (S), R24.2, U7.1 (SCLK)
unnamed: R1.1, U2.3 (I0)
unnamed: R1.2, U1.4 (Y)
unnamed: R2.1, U2.4 (Z)
unnamed: R3.1, U3.2 (A)
unnamed: R4.2, SW1.4 (A)
unnamed: R5.1, U2.1 (I1)
unnamed: R5.2, U4.4 (Y)
unnamed: R6.2, SW1.6 (C)
unnamed: R10.1, U4.2 (A)
unnamed: R10.2, U6.4
unnamed: R9.2, R11.1, U5.4, U6.2
unnamed: R17.2, U7.2 (GPO0/SWIFMODE)
unnamed: R20.2, U7.5 (CSB/GPO1)
unnamed: R21.1, U7.16 (MCLK)
unnamed: R21.2, TP2.1
unnamed: R22.1, U7.15 (LRCLK)
unnamed: R23.1, U7.14 (BCLK)
unnamed: R26.1, U7.13 (DIN)
unnamed: R27.2, U7.12 (DOUT)
unnamed: R31.2, U7.4 (SDOUT/GPO2)
unnamed: R32.2, U8.4 (Y)
unnamed: R33.1, U8.2 (A)
unnamed: SW1.5 (B), U2.6 (S)
unnamed: TP8.1, U7.9 (CLKOUT)

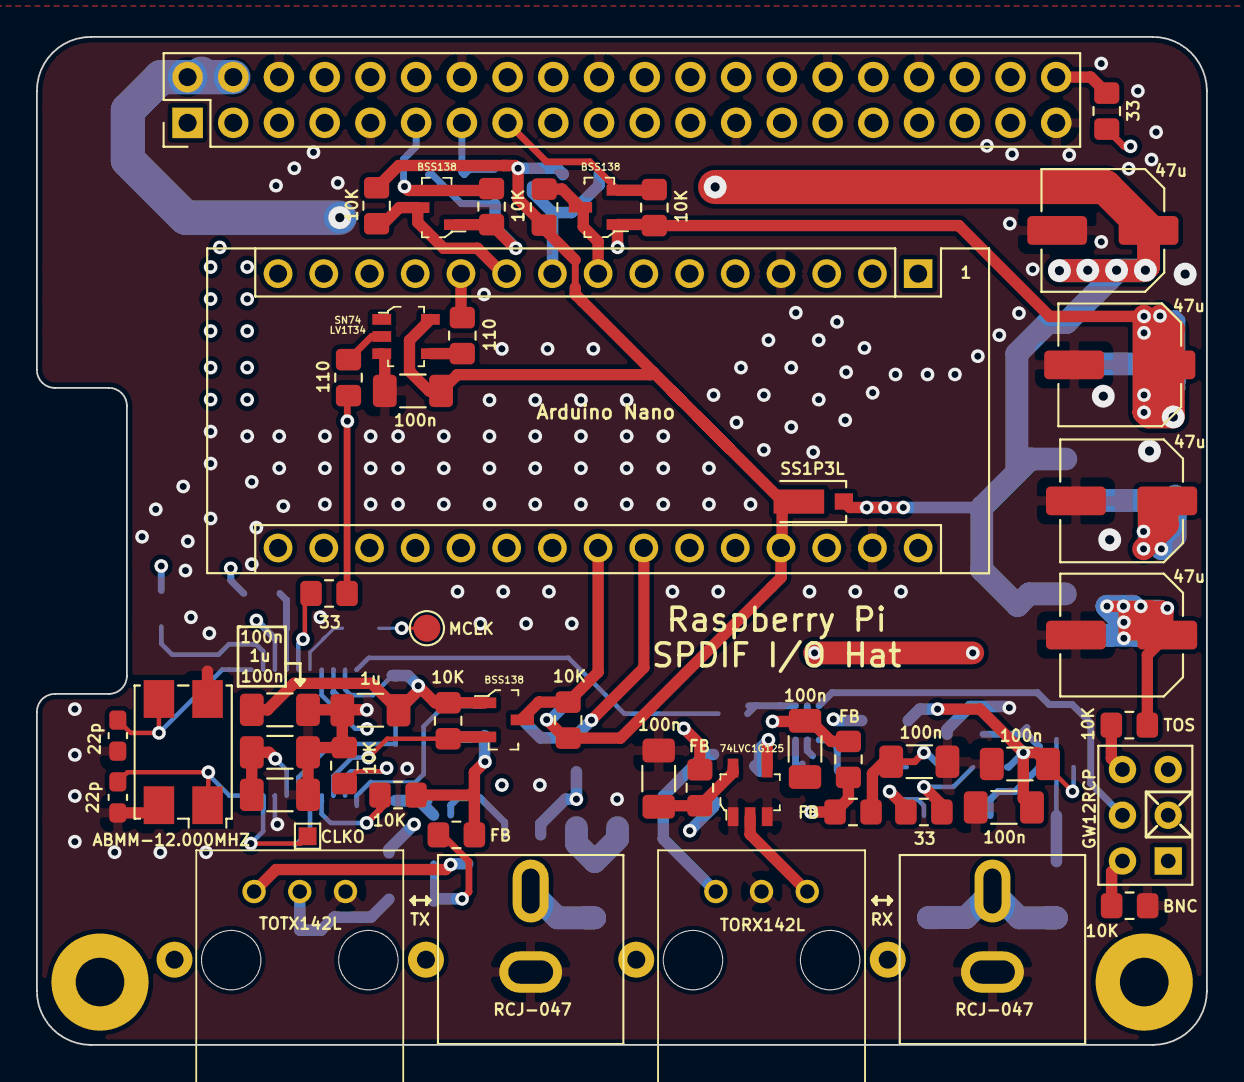
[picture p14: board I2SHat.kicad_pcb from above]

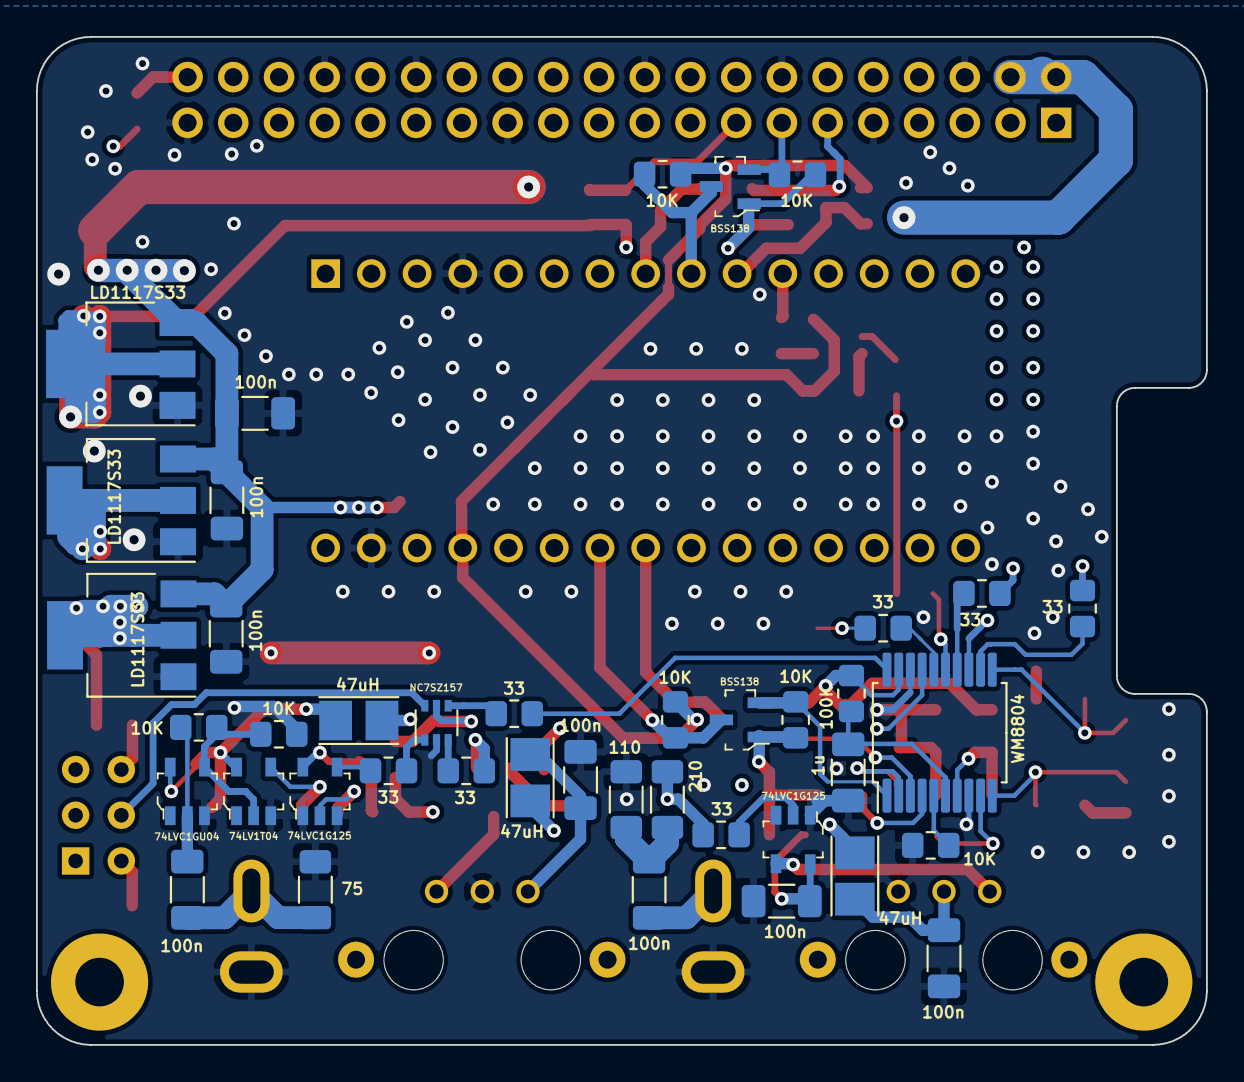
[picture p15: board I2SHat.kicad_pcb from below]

Board: 4 copper layers, 65.0 x 56.0 mm, 98 parts (41 on the bottom side), 63 nets.

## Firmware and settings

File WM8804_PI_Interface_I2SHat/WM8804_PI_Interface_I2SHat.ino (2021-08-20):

//#include <SPI.h>
#include <Wire.h>
//#include <Adafruit_GFX.h>
//#include <Adafruit_SSD1306.h>

//*** OLED Code is Commented Out ***//

//#define SCREEN_WIDTH 128 // OLED display width, in pixels
//#define SCREEN_HEIGHT 32 // OLED display height, in pixels

// Declaration for an SSD1306 display connected to I2C (SDA, SCL pins)
//#define OLED_RESET     -1 // Reset pin # (or -1 if sharing Arduino reset pin)
//Adafruit_SSD1306 display(SCREEN_WIDTH, SCREEN_HEIGHT, &Wire, OLED_RESET);

int wm8804 = 0x3A;  // device wm8804 = 0x3A = 00111010
byte error;
int SPDSTAT, INTSTAT;
float frequency = 44100;
unsigned long count = 0;
bool toggle = 0;
int fs = 0;
byte x = 0;
volatile unsigned int T1capture;
volatile unsigned int lastT1capture;
volatile unsigned int period;

void setup() {
  pinMode(5, OUTPUT);
  pinMode(6, OUTPUT);
  pinMode(7, OUTPUT);
  
  //Default to Unknown Output
  digitalWrite(5, LOW);
  digitalWrite(6, LOW);
  digitalWrite(7, LOW);
  
  //if(!display.begin(SSD1306_SWITCHCAPVCC, 0x3C))
  //{
  //    Serial.println(F("SSD1306 allocation failed"));
  //}
  
  //display.clearDisplay();
  //display.setTextSize(2);
  //display.setTextColor(SSD1306_WHITE);

  Wire.begin();
  Serial.begin(9600);
  Wire.beginTransmission(wm8804);
  error = Wire.endTransmission();

  if (error == 0)
  {
    Serial.println("wm8804 found!");
  }
  else if (error == 4)
  {
    Serial.println("Unknown error at address 0x3A");
  }
  else
  {
    Serial.println("No response from wm8804!");
  }

  Serial.print("Device ID: ");
  byte c = ReadRegister(wm8804, 1);
  if (c < 10) {
    Serial.print('0');
  }
  Serial.print(c, HEX);

  c = ReadRegister(wm8804, 0);
  if (c < 10) {
    Serial.print('0');
  }
  Serial.print(c, HEX);

  Serial.print(" Rev. ");
  c = ReadRegister(wm8804, 2);
  Serial.println(c, HEX);
  delay(45000);
  DeviceInit(wm8804);
}

void loop()
{
  INTSTAT = 0;
  while (INTSTAT == 0) {
    if (fs == 0) {                      // in case SR reading is erratic...
      identifySR () ;                   // updates with new SR reading
      //Serial.print ("SR=");
      //Serial.println (fs);
    }
    //Serial.println("INTSTAT");
    //Serial.print ("SR=");
    //Serial.println (fs);
    delay(100);
    INTSTAT = ReadRegister(wm8804, 11); // keep polling (and clearing) interrupt register
  }                                     // until there is an interruption

  // identify what had triggered the interrupt with wm8804
  // most of these shouldn't happen as they are masked off
  // but still useful for debugging

  if (bitRead(INTSTAT, 0)) {                                  // if there has been status changes...
    SPDSTAT = ReadRegister(wm8804, 12);                       // ...and PLL
    if (bitRead(SPDSTAT, 6)) {                                // has gone unlocked?
      delay(100);
      Serial.println("SPDSTAT 6 HIGH");

      // try again to try to reject transient errors
      SPDSTAT = ReadRegister(wm8804, 12);
      if (bitRead(SPDSTAT, 6)) {                              // has PLL really gone unlocked?
        x = 0 ;
        PLLunlocked(wm8804);                                  // tune and roll RX 'till PLL locking recovers
      }
    }
    else {
      Serial.println("S/PDIF PLL locked");
    }
    identifySR ();
    SpdifTxOn (wm8804);
  }                                                           // if (bitRead(INTSTAT, 0))
  
  if (bitRead(INTSTAT, 1)) {                                         // INT_INVALID
    Serial.println("INT_INVALID");
  }

  if (bitRead(INTSTAT, 2)) {                                         // INT_CSUD
    Serial.println("INT_CSUD");
  }

  if (bitRead(INTSTAT, 3)) {                                         // INT_TRANS_ERR
    Serial.println("INT_TRANS_ERR");
  }

  if (bitRead(INTSTAT, 4)) {                                         // UPD_NON_AUDIO
    Serial.println("UPD_NON_AUDIO");
  }

  if (bitRead(INTSTAT, 5)) {                                         // UPD_CPY_N
    Serial.println("UPD_CPY_N");
  }

  if (bitRead(INTSTAT, 6)) {                                         // UPD_DEEMPH
    Serial.println("UPD_DEEMPH");
  }

  if (bitRead(INTSTAT, 7)) {                                         // UPD_REC_FREQ
    Serial.println("Sample rate changed...");
    //PLLunlocked(wm8804);
  }
}

/***********************************
  // Functions go below main loop //
***********************************/

byte ReadRegister(int devaddr, int regaddr) {                       // Read a data register value
  Wire.beginTransmission(devaddr);
  Wire.write(regaddr);
  Wire.endTransmission(false);                                      // repeated start condition by not sending stop.
  Wire.requestFrom(devaddr, 1); // only one byte
  byte data = Wire.read();
  Wire.endTransmission(true);
  return data;
}

void WriteRegister(int devaddr, int regaddr, int dataval) {         // Write a data register value
  Wire.beginTransmission(devaddr); // device
  Wire.write(regaddr); // register
  Wire.write(dataval); // data
  Wire.endTransmission(true);
}

void DeviceInit(int devaddr) {            // resets, initializes and powers up a wm8804
  // reset device
  WriteRegister(devaddr, 0, 0);

  // REGISTER 7
  // bit 7:6 - always 0
  // bit 5:4 - CLKOUT divider select => 00 = 512 fs, 01 = 256 fs, 10 = 128 fs, 11 = 64 fs
  // bit 3 - MCLKDIV select => 0
  // bit 2 - FRACEN => 1
  // bit 1:0 - FREQMODE (is written by S/PDIF receiver) => 00
  WriteRegister(devaddr, 7, B00000100);

  // REGISTER 8
  // set clock outputs and turn off last data hold
  // bit 7 - MCLK output source select is CLK2 => 0
  // bit 6 - always valid => 0
  // bit 5 - fill mode select => 1 (we need to see errors when they happen)
  // bit 4 - CLKOUT pin disable => 1
  // bit 3 - CLKOUT pin select is CLK1 => 0
  // bit 2:0 - always 0
  WriteRegister(devaddr, 8, B00110000);

  // REGISTER 9
  //set SPDIF RX input levels for each channel
  WriteRegister(devaddr, 9, B11111110);     //LSB = 0 for CMOS RX, 1 for 0.5Vpp RX

  // set masking for interrupts
  WriteRegister(devaddr, 10, B01111110);  // We only care about unlock and rec_freq

  // set the AIF TX
  // bit 7:6 - always 0
  // bit   5 - LRCLK polarity => 0
  // bit   4 - BCLK invert => 0
  // bit 3:2 - data word length => 10 (24b) or 00 (16b)
  // bit 1:0 - format select: 11 (dsp), 10 (i2s), 01 (LJ), 00 (RJ)
  WriteRegister(devaddr, 27, B00001010);

  // set the AIF RX
  // bit   7 - SYNC => 1
  // bit   6 - master mode => 1
  // bit   5 - LRCLK polarity => 0
  // bit   4 - BCLK invert => 0
  // bit 3:2 - data word length => 10 (24b) or 00 (16b)
  // bit 1:0 - format select: 11 (dsp), 10 (i2s), 01 (LJ), 00 (RJ)
  WriteRegister(devaddr, 28, B11001010);

  // SPDIF TX to take AIF (I2S) Data as input
  WriteRegister(devaddr, 21, B01111001);

  // set PLL K and N factors
  // this should be sample rate dependent, but makes hardly any difference
  WriteRegister(devaddr, 6, 7);                  // set PLL_N to 7
  WriteRegister(devaddr, 5, 0x36);                 // set PLL_K to 36FD21 (36)
  WriteRegister(devaddr, 4, 0xFD);                 // set PLL_K to 36FD21 (FD)
  WriteRegister(devaddr, 3, 0x21);                 // set PLL_K to 36FD21 (21)

  delay(50);
  // power up device
  WriteRegister(devaddr, 30, 0x00);
  delay(500);
  Serial.println("INIT COMPLETE!");
}

void PLLunlocked(int devaddr) {
  // PLL unlock service routine
  SpdifTxOff(wm8804);
  Serial.println("S/PDIF PLL unlocked");
  //fs = 0;

  // switch PLL mode and coeff settings around trying to find lock

  while (bitRead(SPDSTAT, 6)) {
    if (toggle) {
      PLLmode192(wm8804);
      SPDSTAT = ReadRegister(devaddr, 12);
      ++x ;
    }
    else {
      PLLmodeNormal(wm8804);
      SPDSTAT = ReadRegister(devaddr, 12);
      ++x ;
    }
    if (x >= 8) {                                     // test 192 and normal mode 4 times each                            
      x=0;                                            // before signalling retry and setting fs=0;
      fs=0;
      Serial.println("Retrying");
    }
  } 
}

void PLLmode192(int devaddr) {
  //Serial.println("trying 192 kHz mode...");
  WriteRegister(devaddr, 6, 8);                  // set PLL_N to 8
  WriteRegister(devaddr, 5, 12);                 // set PLL_K to 0C49BA (0C)
  WriteRegister(devaddr, 4, 73);                 // set PLL_K to 0C49BA (49)
  WriteRegister(devaddr, 3, 186);                // set PLL_K to 0C49BA (BA)
  toggle = 0;
  delay(200);
}

void PLLmodeNormal(int devaddr) {
  //Serial.println("trying normal mode...");
  WriteRegister(devaddr, 6, 7);                  // set PLL_N to 7
  WriteRegister(devaddr, 5, 54);                 // set PLL_K to 36FD21 (36)
  WriteRegister(devaddr, 4, 253);                // set PLL_K to 36FD21 (FD)
  WriteRegister(devaddr, 3, 33);                 // set PLL_K to 36FD21 (21)
  toggle = 1;
  delay(200);
}

ISR (TIMER1_CAPT_vect)
{
  T1capture = ICR1 ;
  period = T1capture - lastT1capture;
  lastT1capture = T1capture ;
}

void prepareForInterrupts ()
{
  noInterrupts ();  // protected code
  TCCR1B = (1 << ICES1) + 1;
  TIMSK1 = (1 << ICIE1) ;
  TCCR1A = 0;
  interrupts ();
}

void identifySR ()
{
  prepareForInterrupts ();
  delay(1);                    // allow time for LRCK pulses to get captured by timer1
  TIMSK1 = (0 << ICIE1) ;      // stop responding the input capture
  //  Serial.print ("Count = ");
  //  Serial.println (period);

  if (period >= 81 && period <= 85) {
//    if (toggle) {
      if (fs != 192){
        Serial.println("192 KHz");
        PLLmode192(wm8804);
        digitalWrite(5, HIGH);
        digitalWrite(6, HIGH);
        digitalWrite(7, HIGH);
        fs = 192 ;
      }
//      display.clearDisplay();
//      display.setCursor(0,0);
//      display.println(F("Frequency:"));
//      display.println(F(" 192kHz"));
//      display.display();
//    }
  }
  else if (period >= 89 && period <= 93) {
//    if (toggle == 0) {
      if (fs != 176){
        Serial.println("176.4 KHz");
        PLLmodeNormal(wm8804);
        digitalWrite(5, HIGH);
        digitalWrite(6, HIGH);
        digitalWrite(7, LOW);
        fs = 176 ;
      }
//    display.clearDisplay();
//    display.setCursor(0,0);
//    display.println(F("Frequency:"));
//    display.println(F(" 176.4kHz"));
//    display.display();
//    }
  }
  else if (period >= 164 && period <= 170) {
//    if (toggle == 0) {
      if (fs != 96){
        Serial.println("96 KHz");
        PLLmodeNormal(wm8804);
        digitalWrite(5, HIGH);
        digitalWrite(6, LOW);
        digitalWrite(7, HIGH);
        fs = 96 ;
      }
//    display.clearDisplay();
//    display.setCursor(0,0);
//    display.println(F("Frequency:"));
//    display.println(F(" 96kHz"));
//    display.display();
//    }
  }
  else if (period >= 177 && period <= 185) { 
//    if (toggle == 0) {
      if (fs != 88){
        Serial.println("88.2 KHz");
        PLLmodeNormal(wm8804);
        digitalWrite(5, HIGH);
        digitalWrite(6, LOW);
        digitalWrite(7, LOW);
        fs = 88 ;
      }      
//    display.clearDisplay();
//    display.setCursor(0,0);
//    display.println(F("Frequency:"));
//    display.println(F(" 88.2kHz"));
//    display.display();
//    }
  }
  else if (period >= 326 && period <= 339) {
//    if (toggle == 0) {
      if (fs != 48){
        Serial.println( "48 KHz");
        PLLmodeNormal(wm8804);
        digitalWrite(5, LOW);
        digitalWrite(6, HIGH);
        digitalWrite(7, HIGH);
        fs = 48 ;
      }
//    display.clearDisplay();
//    display.setCursor(0,0);
//    display.println(F("Frequency:"));
//    display.println(F(" 48kHz"));
//    display.display();
//    }
  }
  else if (period >= 356 && period <= 370) {
//    if (toggle == 0) {
      if (fs != 44){
        Serial.println("44.1 KHz");
        PLLmodeNormal(wm8804);
        digitalWrite(5, LOW);
        digitalWrite(6, HIGH);
        digitalWrite(7, LOW); 
        fs = 44;
      } 
//    display.clearDisplay();
//    display.setCursor(0,0);
//    display.println(F("Frequency:"));
//    display.println(F(" 44.1kHz"));
//    display.display();
//    }
  }
  else if (period >= 490 && period <= 510) {
//    if (toggle == 0) {
      if (fs != 32){
        Serial.println("32 KHz");
        PLLmodeNormal(wm8804);
        digitalWrite(5, LOW);
        digitalWrite(6, LOW);
        digitalWrite(7, HIGH);
        fs = 32;
      }
//    display.clearDisplay();
//    display.setCursor(0,0);
//    display.println(F("Frequency:"));
//    display.println(F(" 32kHz"));
//    display.display();
//    }
  }
  else {
    if (fs != 0){
      Serial.println("Unknown");
      digitalWrite(5, LOW);
      digitalWrite(6, LOW);
      digitalWrite(7, LOW);
      fs = 0;
    }
//    display.clearDisplay();
//    display.setCursor(0,0);
//    display.println(F("Frequency:"));
//    display.println(F(" Unknown"));
//    display.display();
  }
}

void SpdifTxOff(int devaddr) {
  WriteRegister(devaddr, 30, 0x04);              // all up but spdif TX
  delay(10);
}

void SpdifTxOn(int devaddr) {
  WriteRegister(devaddr, 30, 0);                 // all up spdif TX included
  delay(10);
}

void SpdifRxOff(int devaddr) {
  WriteRegister(devaddr, 30, 0x02); // turn off spdif RX
  delay (10);
}

void SpdifRxOn(int devaddr) {
  WriteRegister(devaddr, 30, 0x00); // turn on spdif RX
  delay (10); 
}

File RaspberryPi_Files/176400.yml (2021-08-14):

---
# source: EQ setting for Sennheiser HD650 (Harman AE/OE) by oratory1990 from
# 14.04.21:
# https://www.dropbox.com/s/zr5tqw0qojom9uh/Sennheiser%20HD650.pdf?dl=0
#
# BiQuadDesigner for Free Biquad filters (used instead of shelving fitlers):
# https://arachnoid.com/BiQuadDesigner/index.html

devices:
  samplerate: 176400
  chunksize: 4096
  target_level: 2048
  capture:
    type: Alsa
    channels: 2
    device: "hw:CARD=GenericStereoAu,DEV=1"
    format: S32LE
  playback:
    type: Alsa
    channels: 2
    device: "hw:CARD=GenericStereoAu,DEV=0"
    format: S32LE

filters:
  hd650_oratory1990_gain:
    type: Gain
    parameters:
      gain: -9.3
      
  hd650_oratory1990_band01:
    type: Biquad
    parameters:
      type: Peaking
      freq: 20
      gain: 4.0
      q: 1.1
      
  hd650_oratory1990_band02:
    type: Biquad
    parameters:
      type: Peaking
      freq: 97
      gain: -2.4
      q: 0.7
            
  hd650_oratory1990_band03:
    type: Biquad
    parameters:
      type: Free
      a1: -1.99548524
      a2: 0.99549541
      b0: 1.00084114
      b1: -1.99548074
      b2: 0.99465876
      
  hd650_oratory1990_band04:
    type: Biquad
    parameters:
      type: Peaking
      freq: 215
      gain: -1.8
      q: 1.1  
      
  hd650_oratory1990_band05:
    type: Biquad
    parameters:
      type: Peaking
      freq: 1300
      gain: -1.4
      q: 1.5
      
  hd650_oratory1990_band06:
    type: Biquad
    parameters:
      type: Free
      a1: -1.89027915
      a2: 0.89599317
      b0: 1.40029763
      b1: -2.67126889
      b2: 1.27668528 
       
  hd650_oratory1990_band07:
    type: Biquad
    parameters:
      type: Peaking
      freq: 2700
      gain: -1.3
      q: 3.0
      
  hd650_oratory1990_band08:
    type: Biquad
    parameters:
      type: Peaking
      freq: 3250
      gain: -3.0
      q: 2.7
      
  hd650_oratory1990_band09:
    type: Biquad
    parameters:
      type: Peaking
      freq: 5400
      gain: -1.6
      q: 3.0
      
  hd650_oratory1990_band10:
    type: Biquad
    parameters:
      type: Free
      a1: -1.49835239
      a2: 0.60105437
      b0: 0.74206394
      b1: -1.04575498
      b2: 0.40639303

pipeline:
  - type: Filter
    channel: 0
    names:
      - hd650_oratory1990_gain
      - hd650_oratory1990_band01
      - hd650_oratory1990_band02
      - hd650_oratory1990_band03
      - hd650_oratory1990_band04
      - hd650_oratory1990_band05
      - hd650_oratory1990_band06
      - hd650_oratory1990_band07
      - hd650_oratory1990_band08
      - hd650_oratory1990_band09
      - hd650_oratory1990_band10
  - type: Filter
    channel: 1
    names:
      - hd650_oratory1990_gain
      - hd650_oratory1990_band01
      - hd650_oratory1990_band02
      - hd650_oratory1990_band03
      - hd650_oratory1990_band04
      - hd650_oratory1990_band05
      - hd650_oratory1990_band06
      - hd650_oratory1990_band07
      - hd650_oratory1990_band08
      - hd650_oratory1990_band09
      - hd650_oratory1990_band10
   

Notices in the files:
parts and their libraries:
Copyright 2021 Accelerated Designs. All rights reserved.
